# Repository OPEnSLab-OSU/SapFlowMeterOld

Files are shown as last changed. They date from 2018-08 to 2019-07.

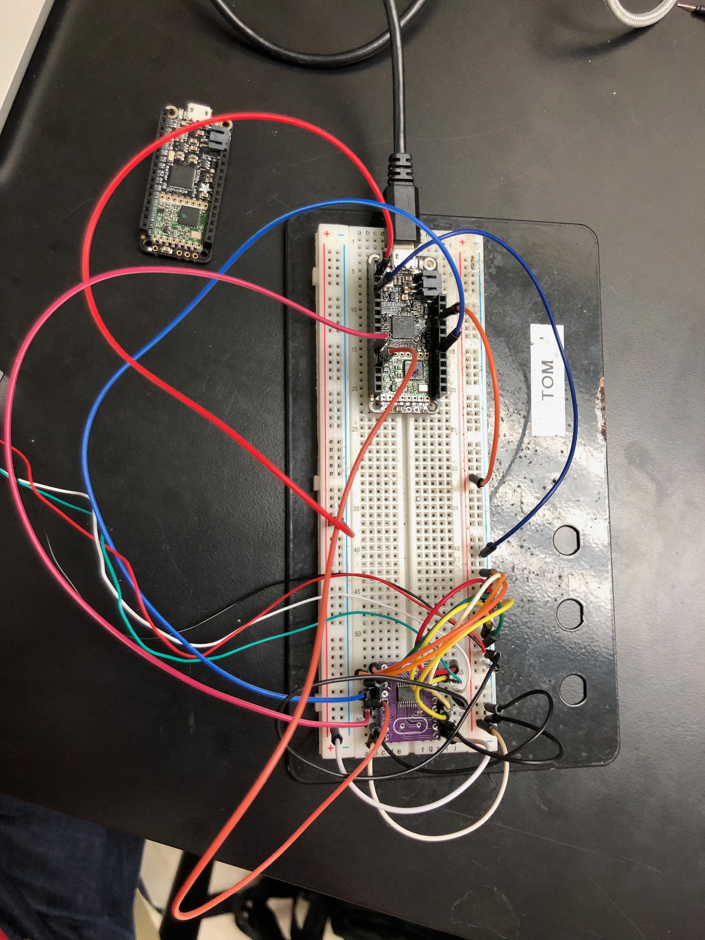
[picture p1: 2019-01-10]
MonitorDMS2/IMG_0117.jpeg

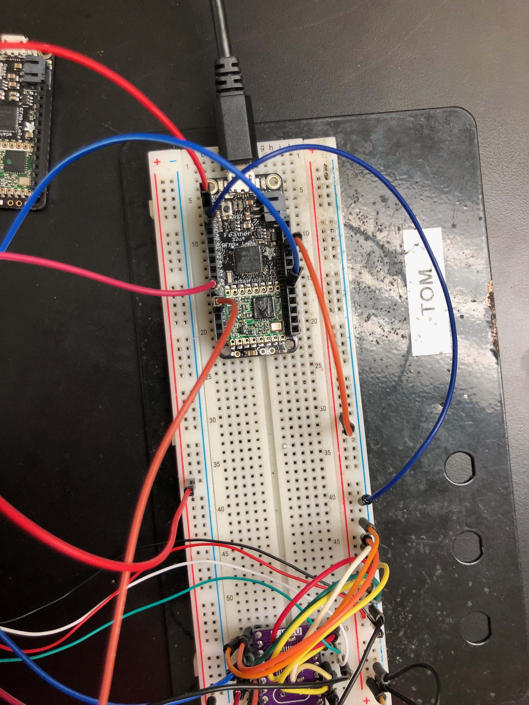
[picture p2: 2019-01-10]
MonitorDMS2/IMG_0116.jpeg

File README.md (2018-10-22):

# Sap Flow Meter

This is the primary location of the Sap Flow Meter project code, which is a modified code of Project LOOM code by OPEnS Lab, and PCB designs, by using EAGLE CAD PCB designing tool.

## Table of Contents

1. [Installation](#installation)
2. [Device Support](#device-support)
3. [Communication Platforms](#communication-platforms)
4. [Device Configuration](#device-configuration)
	1. [Enable sap flow meter](#Enable-sap-flow-meter)
	2. [HUB options](#HUB-options)
	3. [NODE options](#NODE-options)

## Installation

The Loom Library, and any dependencies, need to be placed into the Arduino libraries folder, i.e:

Document > Arduino > Libraries

## Device Support

- Arduino Feather M0

## Communication Platforms

WiFi and LoRa have had the most attention in development and thus have the most support and options, especially WiFi, as that is currently the only to communicate with a computer running Max/MSP. Other platforms have been implemented however. Below is the table of device inputs and outputs currently implemented, planned, or in consideration (bold for well implemented, * if partially implemented or in need of testing to be considered well implemented, plaintext if planned but not implemented, ? if in consideration). The top section is device-device communication platforms, and the bottom section are platforms that do not necessarily transmit directly to another Loom device

| Inputs | Outputs | Comments |
| --- | --- | --- |
| **LoRa** | **LoRa** | Implemented | 
| Ethernet | Ethernet* | Currently only used with hubs, expansion in progress |
| GSM | GSM* | Currently only one device, so outputs MQTT via GSM, but no GSM receiving yet |
| Google Sheets  | Google Sheets (PushingBox)* | Works as output, looking for ways of improving the pipline |
| SD card | **SD card** | Works as output, considering as input |
| Serial | **Serial** | Works for output. Serial as input may or may not be useful (is how Fona is tested) |

## Device Configuration

The configuration of the code to upload and flash to devices is set in the config.h file. This file presents the options that can be set or toggled to achieve a particular behavior. The preprocessor uses these definitions to select the necessary declarations, variables, and functions automatically. 

Currently changes to the config need to be done manually in the file itself.

The configuration file is used in conjunction with preprocessor statements to essentially built the specificed sketch. Any options that can be set or toggled, or any specification of hardware (e.g. relay switch for HRM, and analog sensor for NTC thermistors) being used occur in (and only in) this config.h.

### Enable sap flow meter

Firstly, it is necessry to toggle "is_sapflow"

```cpp
// --- Prebuilt Devices ---
#define is_ishield      0	// 1 to specify using Ishield (should enable only wifi as communication platform)
#define is_multiplexer  0	// 1 if tca9548a Multiplexer is being used. (Further customization in advanced options)
#define is_sapflow      1 
#define is_evaporimeter 0
```

### Manipulate options

Set ether HUB or Node(probe meter)

### HUB options
- Set hub_node_type to be 0
- Set CHANNEL to be 1 - 8
- Set is_lora to be 1 if you want to communicate to receive data from node through LoRa. Default is 1.
- Set is_rtc to be 1 if you want to log timestamp
- Set is_sd to be 1 if you want to store recieved data in micro sd card
- If you want to rename excel file to be stored in the sd card, change char FileName[] = "file_name.CSV"; The file name should be short length to avoid any miscellenous error.

```cpp
// --- Sapflowmeter Options ---
#if is_sapflow == 1
	#define hub_node_type    0      // 0: hub, 1: node
  #define probe_type       0      // 0: TDM, 1: HRM
  #define sensor_type      1      // 0: NTC, 1: RTD
  #define CHANNEL          1      // Channel to use. Set to 1-8 for channels A-H, respectively. Alternatively can define to -1 to used advanced option INIT_INST
  #define REQUEST_SETTINGS 0      // 1 to request channel settings from Max Channel Manager, 0 to not
  #define AUTO_NAME        0      // 1 to enable naming device based on configured settings (if not set manual name in advanced options)
  #define is_lora          1      // enable LoRa
  #define is_rtc           1      // enable rtc
  #define is_sd            1      // enable microsd logger
   char FileName[]       =     "HUB1019.CSV";
```

- set is_ethernet to be 1 if you want to send data through ethernet
- set is_fona to be 1 if you want to send data through 2G network
- set is_pushingbox 1 if you want to store data in google sheet
- To store data in google sheet, it is necesary to define spreadsheet ID of google sheet that you want use and device ID. There is detail directions to setup pushingbox and googlesheet in the next section.

```cpp
  #if hub_node_type == 0       // if is hub
    #define is_ethernet   0
    #define is_fona       1
    #define is_pushingbox 1
    #if is_pushingbox == 1
      #define spreadsheet_id "17XjrTjXENChYsHMVvKgePg8rsohwz0hyASkdeZZKROk"   // This is Dongjun's Sapflow spreadsheet
      char device_id[]   =   "v4099B684340616E";
    #endif // of is_pushingbox
  #elif hub_node_type == 1     // if is node
  .
  .
  .
  ```
### NODE options

- Set hub_node_type to be 1
- Set probe_type to be 0: TDM or 1:HRM
- Set sensor_type to be 0: NTC thermister or 1: RTD sensor. There will be more options for other sensors(eg. k type thermometer) later.
- Set CHANNEL to be 1 - 8
- Set is_lora to be 1 if you want to communicate to send data to HUB through LoRa. Default is 1.
- Set is_rtc to be 1 if you want to log timestamp
- Set is_sd to be 1 if you want to store measured data in micro sd card
- If you want to rename excel file to be stored in the sd card, change char FileName[] = "file_name.CSV"; The file name should be short length to avoid any miscellenous error.

```cpp
// --- Sapflowmeter Options ---
#if is_sapflow == 1
  #define hub_node_type    1      // 0: hub, 1: node
  #define probe_type       0      // 0: TDM, 1: HRM
  #define sensor_type      1      // 0: NTC, 1: RTD
  #define CHANNEL          1      // Channel to use. Set to 1-8 for channels A-H, respectively. Alternatively can define to -1 to used advanced option INIT_INST
  #define REQUEST_SETTINGS 0      // 1 to request channel settings from Max Channel Manager, 0 to not
  #define AUTO_NAME        0      // 1 to enable naming device based on configured settings (if not set manual name in advanced options)
  #define is_lora          1      // enable LoRa
  #define is_rtc           1      // enable rtc
  #define is_sd            1      // enable microsd logger
   char FileName[]       =     "TDM0731.CSV";
```

- Set is_sht31d to be 1 if you want to measure ambient temperature and humidity
- Set is_decagon to be 1 if you want to use soil moisture sensor
- If you use HRM probe, you can modify heat pulse duration. Default is 2.5 sec. The heater turns on for 2.5 sec and turn off for 2.5 sec repeatedly during heat duration.
- If you want to change data transmission interval, modify senddelay. 60000 for 1 min, 900000 for 15 min, 1800000 for 30 min. Default is 900000.
- If you want to change heat duration(Period that heater turns on),  change heatduration. Defualt for TDM is 240000(4 min), and for HRM is 120000 (2 min). The heater is turned on before data transmission time for the heat duration and turned off 1 min after data transmission. (For example, let's assume the code was initialized at 13:00. If senddelay is 15 min and heatduration is 4min, the heater is turned on at 13:11(4 mins before send interval). Probe meter measures and sends data at 13:15. The heater is turned off at 13:16. After this iteration, the heater is turned on again at 13:26. It sends data at 13:30. The heater is turned off at 13:31. Repeat this process until the battery is dead or probe meter is off)

```cpp
  .
  .
  .
  #elif hub_node_type == 1     // if is node
    #define num_analog    2      // two temperature sensors
    #define is_sht31d     1      // Ambient Temperature / Humidity
    #define is_decagon    1      // Soil moisture
    #define heatpulse     2500   // For HRM probe heat pulse (e.g 2500:2.5 sec) 
    #define senddelay     900000 // send data every 2500(=2.5s), 60000(=1m), 300000ms(=5m), 600000ms(=10m), 900000ms(=15m)
    #if probe_type == 0      // 0:TDM, 1: HRM
      #define heatduration  240000  // Turn on heater for 4 min
    #elif probe_type == 1
      #define heatduration  120000  // Turn on heater for 2 min
    #endif //of probe_type
  #endif // of hub_node_type
```

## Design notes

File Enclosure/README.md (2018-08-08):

# Sap Flow Meter: CAD

## Table of Contents

1. [Sap flow meter Top](https://a360.co/2OUiD7d)
2. [Sap flow meter Bottom](https://a360.co/2OUiD7d)

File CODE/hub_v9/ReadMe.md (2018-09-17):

# Project Loom: Library

This is the primary location of the Project LOOM code, consolidated into place with a single Arduino .ino sketch built with code selected by the preprocessor based on the configuration file. 

## Table of Contents

1. [Installation](#installation)

2. [Device Support](#device-support)

3. [Communication Platforms](#communication-platforms)

4. [Device Configuration](#device-configuration)

5. [Max/MSP](#max/msp)

6. [Library Architecture](#library-architecture)
    1. [Overall Structure](#overall-structure)
        1. [Example Library Include Hierarchy](#example-library-include-hierarchy)
    2. [Adding to the Library](#adding-to-the-library)
    3. [Adding to the Message Router](adding-to-the-message-router)

7. [Channels](#channels)
    1. [Implementation](#implementation)
    2. [Additional Devices](#additional-devices)

8. [Configuration File](#configuration-file)

9. [API](#api)
    1. [Includes](#includes)
    2. [Setup](#setup)
    3. [Main Loop Functions](#main-loop-functions)
        1. [Receive Bundle](#receive-bundle)
        2. [Process Bundle](#process-bundle)
        3. [Measure Sensors](#measure-sensors)
        4. [Package Data](#package-data)
        5. [Send Bundle](#send-bundle)
        6. [Additional Loop Checks](#additional-loop-checks)
        	. [Minimal Working Example](#minimal-working-example)	

10. [SD Card Support](#sd-card-support)

11. [Real-Time Clock Support](#real-time-clock-support)

12. [Arduino IDE Setup](#arduino-ide-setup)

13. [Building and Uploading Code Without The IDE](#building-and-uploading-code-without-the-ide)

14. [Configuration Conflicts](#configuration-conflicts)

## Installation

The Loom Library, and any dependencies, need to be placed into the Arduino libraries folder, i.e:

Document > Arduino > Libraries

## Device Support

- Adafruit Feather M0
- Adafruit Feather 32u4

## Communication Platforms

WiFi and LoRa have had the most attention in development and thus have the most support and options, especially WiFi, as that is currently the only to communicate with a computer running Max/MSP. Other platforms have been implemented however. Below is the table of device inputs and outputs currently implemented, planned, or in consideration (bold for well implemented, * if partially implemented or in need of testing to be considered well implemented, plaintext if planned but not implemented, ? if in consideration). The top section is device-device communication platforms, and the bottom section are platforms that do not necessarily transmit directly to another Loom device

| Inputs | Outputs | Comments |
| --- | --- | --- |
| **WiFi** | **WiFi** | Implemented |
| **LoRa** | **LoRa** | Implemented |
| nRF* | nRF* | May need more testing to be 'proven' |
| Ethernet | Ethernet* | Currently only used with hubs, expansion in progress |
| GSM | GSM* | Currently only one device, so outputs MQTT via GSM, but no GSM receiving yet |
| Bluetooth | Bluetooth | Planned |
| | | |
| Google Sheets? | Google Sheets (PushingBox)* | Works as output, looking for ways of improving the pipline |
| Adafruit IO* | Adafruit IO* | Could use more robust integration |
| IFTTT? | IFTTT? | Currently, IFTTT works only as output though Adafruit IO |
| SD card? | **SD card** | Works as output, considering as input |
| Serial? | **Serial** | Works for output. Serial as input may or may not be useful (is how Fona is tested) |

## Device Configuration

The configuration of the code to upload and flash to devices is set in the config.h file. This file presents the options that can be set or toggled to achieve a particular behavior. The preprocessor uses these definitions to select the necessary declarations, variables, and functions automatically. 

Currently changes to the config need to be done manually in the file itself. A script to automate this process from the command line, and ultimately Max, is in progress.

## Max/MSP

The associated [Loom Data Processors](https://github.com/OPEnSLab-OSU/InternetOfAg/tree/master/Max) and control modules are made as patches in Max/MSP. The Max interfaces are not strictly necessary for using this library, but provide convenient features and means of interacting with your Loom devices / network.

## Librarary Architecture

The LOOM Library is the answer to the growing set of code to drive Project LOOM's supported devices, hardware, and communication platforms. The set of possible combinations of device configurations makes it unfeasable for LOOM developers and users alike to manage sketches with desired functionality. Instead, a configuration file effectively creates the desired sketch dynamically. A loom_preamble file selects entire files to include, each of which may also contain additional preprocessor statements.

### Overall Structure

The LOOM Library is effectively an aggregate of all of the functionality possible within the entirety of the supported devices, sensors, and actuators. The user then specifies the needs of their sketch inside the config.h. Based on the needs of the sketch, the requisite files, functions, and logic will be dynamically included such that only what is needed by the sketch is uploaded to the device. loom_preamble.h uses config.h to know which files to include, these files in turn then include the libraries they need. loom_common.h is also always present as it has the LOOM_begin() function, which sets up all the modules and sensors being used by the sketch. 

#### Example Library Include Hierarchy

The hierarchy of included files looks something like the following (example if building for Ishield device on Feather M0 WiFi). 

**Note** – bolded are files that are always necessary and thus included, independent of config.h. In angle brackets are non-Loom dependencies.

- Ishield_Example.ino
  - **Config.h**
  - **Loom_preamble.h** (likely to be renamed)
    - **<OSCBundle.h>**
    - Loom_translator.h
    - <Adafruit_SleepyDog.h>
    - <SPI.h>
    - loom_analog.h
    - loom_neopixel.h
      - <Adafruit_NeoPixel.h>
    - loom_mpu6050.h
      - <I2Cdev.h>
      - <Wire.h>
      - <MPU6050_6Axis_MotionApps20.h>
    - loom_wifi.h
      - <WiFi101.h>
      - <WiFiUDP.h>
    - **loom_flash.h**
      - <FlashStorage.h>
    - **loom_common.h**

### Adding to the Library

New sensor and actuator support can be added by filling out the loom_mod_template.h file with relevant code. This template ensures that the code for each piece of hardware conforms to a standard format, making it easier to read and understand.

New files should be added #included in the loom_preamble.h file after config.h but generally before loom_flash.h and loom_common.h.

There are plans/consideration for a script that will handle most of the additions for a user based on various provided parameters / needs as current additions generally need to modify the config, preamble, loom_commom (sometimes), and loom_interface files in a mostly boiler plate fashion in addition to the new device-specific file.

### Message Router

#### Intro to Route and Dispatch of Message Router

Custom functions can be added to the message router. The message router is called via:

```
bndl->route(configuration.packet_header_string, msg_router);
```

From the `process_bundle` function in the 'loom_interface.h' file. The message router checks any OSC messages that it receives, and if the message's address string matches one of the dispatch calls in the router, then the message gets forwarded to a function designed to handle / process messages with that address string. This usually entails reading the arguments to the message (which should be sent in an order / format known by the function that will handle the processing).

The dispatch calls in the message router take the following form:

```
msg.dispatch("/address", processing_function, addrOffset);
```

An example of a dispatch that takes a message that has an address of the device identifying string followed by "setID", and calls a function `set_instance_num` (which sets the device instance number) would be:

```
msg.dispatch("/SetID", set_instance_num, addrOffset);
```

The reason only the `/SetID` is provided and not something like `/LOOM/Ishield7/SetID` is because the aforementioned route function checks for message addressed to the device, which in this case is identified by `/LOOM/Ishield7`, and passes only the remaining part of the address to the message router. Messages that do not start with the device indentifying string are not sent to the message router.

#### Adding Custom Functions to Message Router

There are a few steps that must be followed in order to get a custom function to be callable by the message router. These are:

- Write your function in the correct format
- Add the function prototype to the top of loom_msg_router.h file
- Add the dispatch call to the msg_router function

**Writing Your Function**

All function that are called by the message router need to take only an OSC message by reference, and return nothing. Thus a function skeleton would look like:

```
void your_function(OSCMessage &msg)
{
	// process the message forwarded from msg_router
}
```

Inside this function is generally where you will process the message (if you need, you can add auxiliary function(s), to do some of the processing/handling - these do not have constraints on the parameters or return value). The following OSC methods are recommended for extracting the arguments from the message. (The below list is not exhaustive, see the [OSC API](https://github.com/CNMAT/OSC/blob/master/API.md) for more functions)

**`msg.size()`** Returns the number of arguments in the the message

**`msg.getType(index)`** Returns the type of the argument at `index`, `i` for integer, `f` for float, and `s` for string. Useful in combination with switch statement to select which of the following three functions to call.

**`msg.getInt(index)`** Returns argument to message that is an integer at `index` if argument is indeed an integer and there is an argument at that index

**`msg.getFloat(index)`**Returns argument to message that is a float at `index` if argument is indeed a float and there is an argument at that index

**`msg.getString(index)`**Returns argument to message that is a string at `index` if argument is indeed a string and there is an argument at that index

**`msg.getAddress(buf, 0);`** Copies address of message into char array called `buf`

**Adding the Function Prototype**

Add the protype of the function you wrote, e.g:

```
void your_function(OSCMessage &msg);
```

to the `Custom Function Prototypes` section at the top of the `loom_msg_router.h` file. (Don't forget the semicolon). Should be no need to add the prototypes for any auxililary functions called by the `your_function`.

**Adding the Dispatch Call**

At the bottom of the message router, add:

```
msg.dispatch("/command/string", your_function, addrOffset);
```

Where

-  `/commmand/string` is the section after the device identifying string that is being used to select which function to dispatch a message to. This should be descriptive but not overly long. In the above example,  the string `setID` was used to check if the message should be forwarded to `set_instance_num`
- `your_function` is the name of the function you want to be called if the message matches the device identifying string and command string.
- `addrOffset` should stay as it is, this is an integer value passed in from the `bndl->route(...)` call, and simply specifies where in the message string to start looking for the command section (i.e. right after the device identifying string)

## Channels

The LOOM library and associated Max/MSP processors are designed to use channel based interfaces by default. Channel interfaces abstract device instance number, UDP port, and IP address into a single letter A, B, C, … H. 

The channels are purely a convenience, and the devices can operate without any notion of channels in the firmware and/or Max patches.

### Implementation
A common port is used for the communication of device settings in order to allow the Max patches to communicate with devices in a consistent manner if the instance number, UDP port, or IP (i.e. the channel information) address are unknown.

**Common Port:** 9440 

**Device Unique Channnel Data:** 9441 – 9448

Channel A:	Instance # = 1		UDP Port = 9441	

Channel B:	Instance # = 2		UDP Port = 9442

• • •

Channel H:	Instance # = 8		UDP Port = 9448

**IP Address:** Automatically assigned to devices by one's router. Max interfaces will automatically fetch IP address of selected device. If not using the channels feature implemented in the Loom Max interfaces, then Loom Debug mode may need to be enabled, or the user may need to add custom code, in order to obtain the device's IP address.

### Additional Devices

The Max interfaces presently support 8 concurrent channels, the library itself poses no such restrictions and using custom Max interfaces can allow for the control of more devices.

## Configuration File

The configuration file is used in conjunction with preprocessor statements to essentially built the specified sketch. Any options that can be set or toggled, or any specification of hardware (e.g. sensors and actuators) being used occur in (and only in) this config.h.

Any options for custom additions to the library should be added only to the configuration file.

The config.h file needs to be included before the library itself, so that the configuration can be used to define the necessary subset of the library.

## API

### Includes

Only the configuration and the library are necessary in the .ino sketch. All necessary dependecies of the Loom Library are automatically included. 

**Note:** The config.h file must precede the library

```cpp
#include "config.h"
#include "loom_preamble.h"
```

### Setup

All Loom and device setup is called dynamically within Loom_begin(). A simple setup function would simply be:

```cpp
void setup() 
{
	Loom_begin();	
    
    // Any custom setup code
}
```

### Main Loop Functions

The Loom Library has six primary interface function to call. With just these, a fully functional sketch can be made. Custom code can be inserted before, between, and after any of the interface functions, but changing the relative ordering of the interface functions is not recommended unless you know what you are doing.

#### Receive Bundle

Fills an OSC bundle with packets received the specified platform if data exists and platform is enabled.

```cpp
// Receive bundles
//  takes bundle to be filled and wireless platforms [WIFI, LORA, NRF]
receive_bundle(&bndl, WIFI);
```

- **bndl** – The bundle to fill
- **platform** – The wireless platform to receive on, the values are encoded to a Platform enum to reduce chance for errors

#### Process Bundle

Examine the provided OSC bundle (presumably filled via receive_bundle(). If bundle is not empty,  has no errors, and is addressed to this device, then attempt to perform action specified.

```cpp
// Process bundle (nothing will happen if bndl is empty), bundle is emptied after processing
process_bundle(&bndl);
```

- **bndl** – The bundle to be processed

#### Measure Sensors

Update stored readings from sensors by calling measure on each enabled sensor.

```cpp
// Update stored readings from sensors
measure_sensors();
```

#### Package Data

Fill the provided OSC bundle with latest stored sensor readings

```cpp
// Populate bundle to send with sensor values
package_data(&send_bndl);
```

- **send_bndl** – The OSC bundle to be filled

#### Send Bundle

Sends a packaged bundle on the specified platform

```cpp
// Send the bundle
//  takes bundle to be filled and wireless platforms [WIFI, LORA, NRF]
send_bundle(&send_bndl, WIFI);
```

- **bndl** – The bundle to be sent
- **platform** – The wireless platform to send on, the values are encoded to a Platform enum to reduce chance for errors

#### Additional Loop Checks

Performs any miscellaneous Loom tasks that happen each loop iteration, but are not handled by any of the other 5 interface functions, such as delays between loop iterations and checking a device button has been held for a set amount of time.

```cpp
// Loop checks and sleep between iterations if enabled
additional_loop_checks();
```

### Minimal Working Example

This example is fully functional. It assumes that WiFi has been specified as a wireless communication platform in the config.h file.

```cpp
#include "config.h"
#include "loom_preamble.h"

void setup() 
{
	Loom_begin(); // LOOM_begin calls any relevant LOOM device setup functions
	// Any custom setup code
}

void loop() 
{
	OSCBundle bndl, send_bndl; 
	
	receive_bundle(&bndl, WIFI);
	process_bundle(&bndl);
	measure_sensors();
	package_data(&send_bndl);
	send_bundle(&send_bndl, WIFI);
	additional_loop_checks();
} 
```

## SD Card Support

The Loom library extends the Arduino SD library to have more features, mostly tailored towards using common data structures used by the library.

Namely, support for printing:

- Single elements (int, floats, c-strings, Strings)
- Arrays (ints, floats, c-strings, Strings)
- Bundles (single or multi-msg format)

Additionally, if used with MaxMSP, there is support for sending commands to enable / disable the logging of bundles the device receives (also works without Max).

## Real-Time Clock Support

The Loom library supports two RTC devices:

- Adafruit DS3231 
- Adafruit PCF8523

Currently, interrupts are only supported via the DS3231, with the PCF8523 mostly being used in conjunction with an SD card (as Adafruit Adalogger featherwing has PCF8523 and SD card holder) to provide timestamps.

The Loom Library has support for both devices for returning strings of the date, time, or weekday. Additional timer functions are provided for the DS3231.

## Arduino IDE Setup

Make sure to download the dependencies of the Loom Library from:

https://github.com/OPEnSLab-OSU/InternetOfAg/tree/master/Dependencies 

and install the libraries with the Arduino IDE, as described here:

https://www.arduino.cc/en/guide/libraries

## Building and Uploading Code Without The IDE

Work is currently be done on investigating and implementing a script that will build the config.h file from the command line, taking the options as arguments. A corresponding Max interface will be made to provide a GUI to these options. The interface will pair with the one to subsequently build and upload code to devices.

The design is planned to be as follows:

- Generate the config file from command line 
  - Arguments to used set options, have default values if none specified
  - Sent to a Python script, inserting the parameters in the relevant locations of the config file
- Be able to call this script from Max
- Use Max to create a graphical interface of toggles / inputs corresponding to the script arguments.
  - Error checking (i.e., of selection conflicts) can be performed in the script or Max, but would doing so in Max would give users immediate feedback on invalid combinations

## Configuration Conflicts

The following combinations of options in the configuration file result in various conflicts (e.g. of dependencies) that are known to result in errors or undefined behavior. Such conflicts are also mentioned in the config.h file itself.

- LoRa + nRF
- is_sleep_period + LoRa (Adafruit_ASFcore-master/tc_interrupt.c:140: multiple definition of 'TC3_Handler')

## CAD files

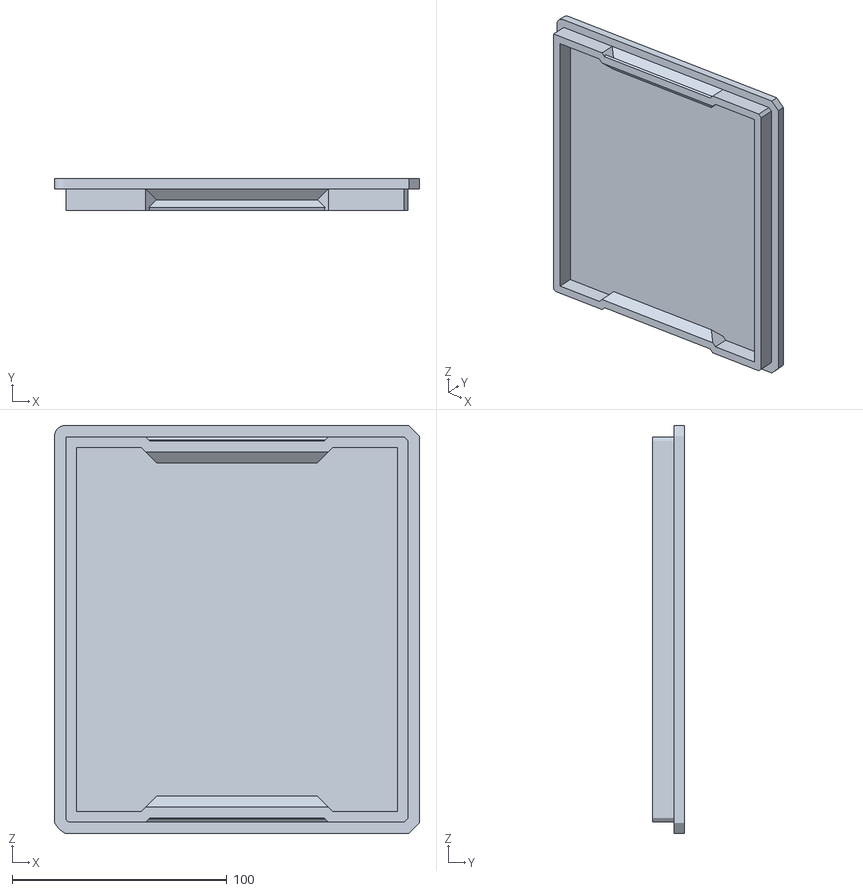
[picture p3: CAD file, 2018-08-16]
Enclosure/Sap_Base_Top_v2.stl
170.0 x 15.0 x 190.0

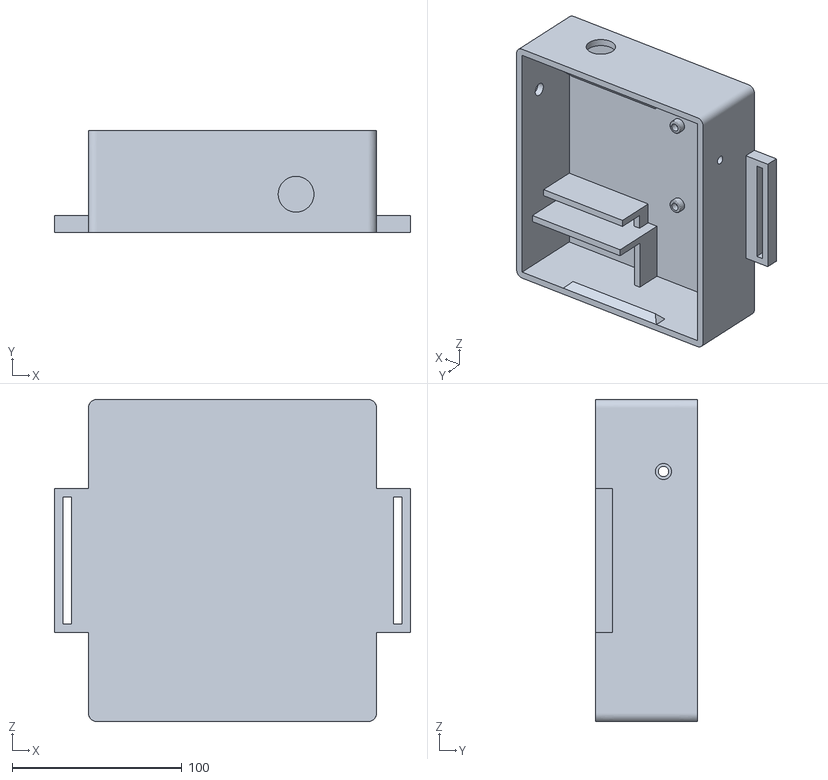
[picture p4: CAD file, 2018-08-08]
Enclosure/Sap_Base_Bottom_v2.stl
210.0 x 60.0 x 190.0

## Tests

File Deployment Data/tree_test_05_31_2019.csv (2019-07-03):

K-Type Top (C) | K-Type Bottom (C) | Set Count | Total Count
K-Type Top (C) | K-Type Bottom (C) | Set Count | Total Count
K-Type Top (C) | K-Type Bottom (C) | Set Count | Total Count
K-Type Top (C) | K-Type Bottom (C) | Set Count | Total Count
K-Type Top (C) | K-Type Bottom (C) | Set Count | Total Count
K-Type Top (C) | K-Type Bottom (C) | Set Count | Total Count
K-Type Top (C) | K-Type Bottom (C) | Set Count | Total Count
K-Type Top (C) | K-Type Bottom (C) | Set Count | Total Count
K-Type Top (C) | K-Type Bottom (C) | Set Count | Total Count
22.13 | 21.38 | 22.02 | 21.52 | 21.98 | 21.27 | 21.91 | 21.21 | 21.77 | 20.98 | 21.73 | 20.82 | 1 | 0
K-Type Top (C) | K-Type Bottom (C) | Set Count | Total Count
21.50 | 20.38 | 21.43 | 20.30 | 21.59 | 20.35 | 21.52 | 20.24 | 21.44 | 20.23 | 21.38 | 20.48 | 1 | 0
K-Type Top (C) | K-Type Bottom (C) | Set Count | Total Count
K-Type Top (C) | K-Type Bottom (C) | Set Count | Total Count
20.05 | 18.91 | 1 | 1
K-Type Top (C) | K-Type Bottom (C) | Set Count | Total Count
K-Type Top (C) | K-Type Bottom (C) | Set Count | Total Count
K-Type Top (C) | K-Type Bottom (C) | Set Count | Total Count
17.48 | 18.77 | 1 | 1
17.49 | 18.34 | 2 | 2
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

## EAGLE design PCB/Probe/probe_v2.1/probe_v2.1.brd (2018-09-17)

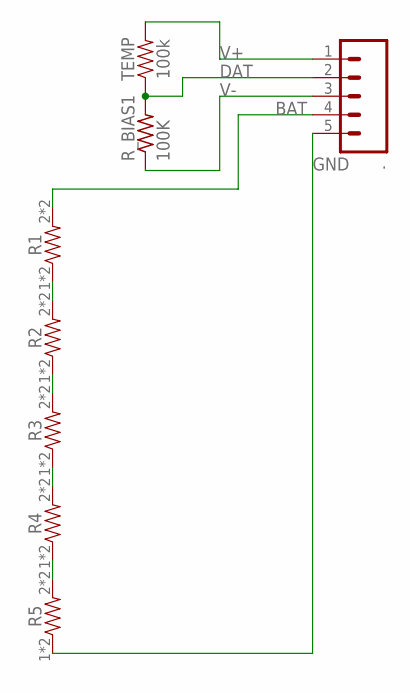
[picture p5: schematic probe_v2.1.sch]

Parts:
.: CONN_05NO_SILK; 1X05_NO_SILK
R1, R2, R3, R4, R5: DRES; 0603
R_BIAS1: 100K; 0805-THM
TEMP: 100k; 0603

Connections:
BAT: ..4, R1.2, R1.P$2 (2)
DAT: ..2, R_BIAS1.2, TEMP.1
GND: ..5, R5.1, R5.P$1 (1)
unnamed: R2.1, R2.P$1 (1), R3.2, R3.P$2 (2)
unnamed: R1.1, R1.P$1 (1), R2.2, R2.P$2 (2)
unnamed: R3.1, R3.P$1 (1), R4.2, R4.P$2 (2)
unnamed: R4.1, R4.P$1 (1), R5.2, R5.P$2 (2)
V+: ..1, TEMP.2
V-: ..3, R_BIAS1.1

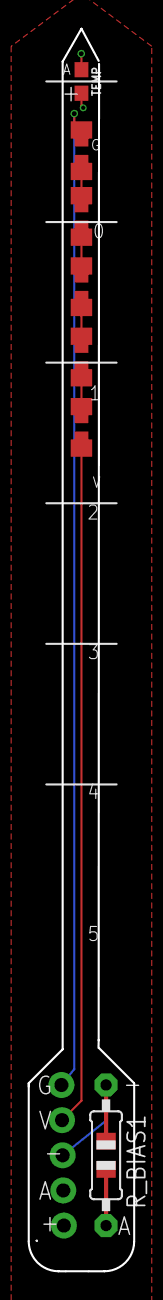
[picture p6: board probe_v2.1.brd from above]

Board: 4 copper layers, 7.6 x 89.8 mm, 8 parts (0 on the bottom side), 9 nets.

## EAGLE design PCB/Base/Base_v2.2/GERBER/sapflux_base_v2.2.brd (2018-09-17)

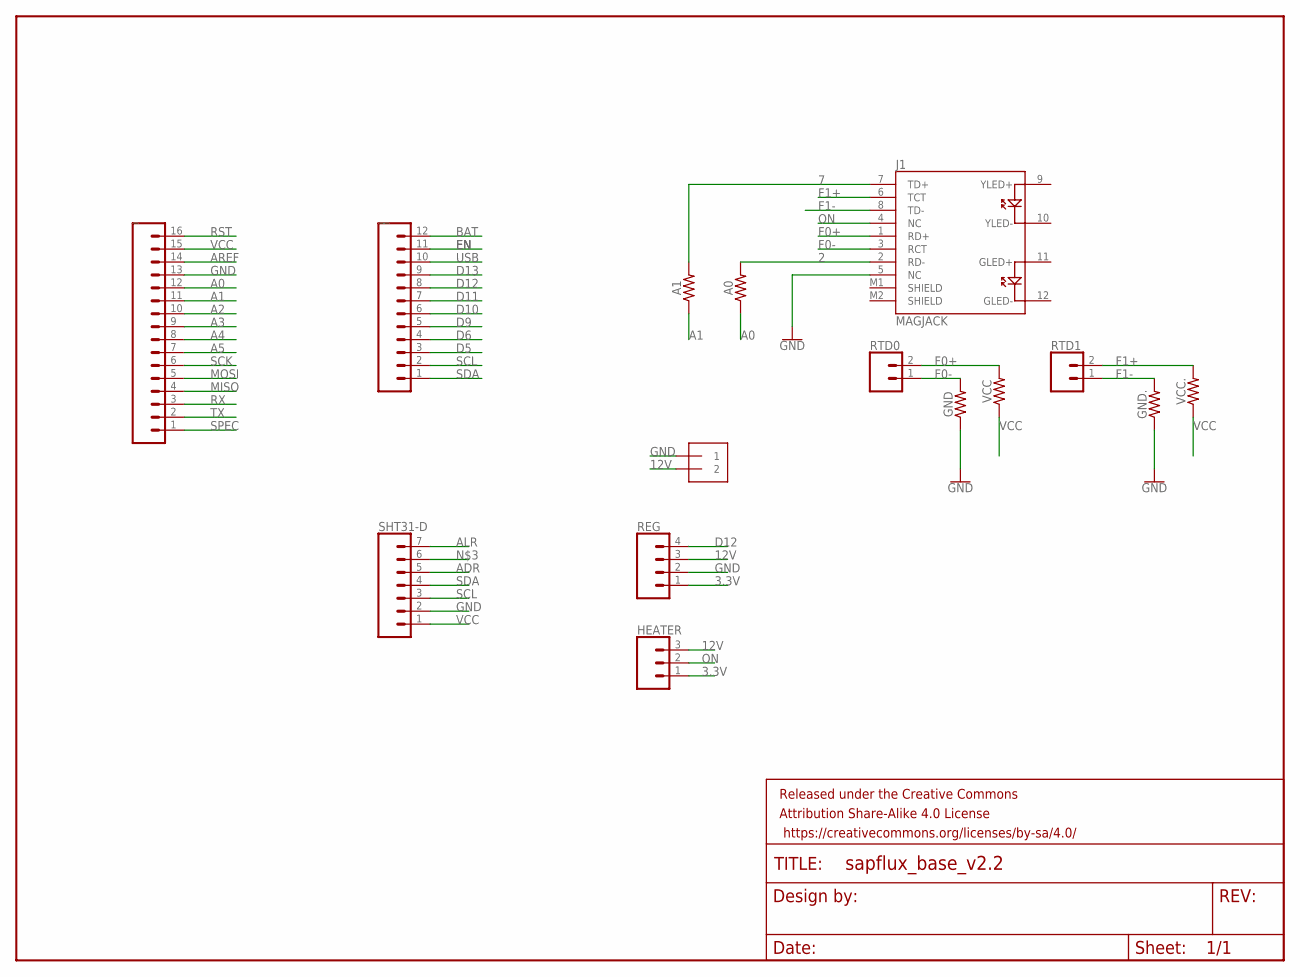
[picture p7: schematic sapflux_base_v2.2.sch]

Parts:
.: 1X2-3.5MM
A0, A1: 1.8MOHM; 0603
FRAME1: FRAME-LETTER; CREATIVE_COMMONS
GND, GND.: 1.8MOHM; 0603
HEATER: CONN_03; 1X03
J1: MAGJACK
REG: CONN_04; 1X04
RTD0, RTD1: CONN_02; 1X02
SHT31-D: CONN_07; 1X07
VCC, VCC.: 1.8MOHM; 0603
_: CONN_16; 1X16
__: CONN_12; 1X12

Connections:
2: A0.2, J1.2 (RD-)
3.3V: HEATER.1, REG.1
7: A1.2, J1.7 (TD+)
12V: ..2, HEATER.3, REG.3
A0: A0.1, _.12
A1: A1.1, _.11
A2: _.10
A3: _.9
A4: _.8
A5: _.7
ADR: SHT31-D.5
ALR: SHT31-D.7
AREF: _.14
BAT: __.12
D5: __.3
D6: __.4
D9: __.5
D10: __.6
D11: __.7
D12: REG.4, __.8
D13: __.9
EN: __.11
F0+: J1.1 (RD+), RTD0.2, VCC.2
F0-: GND.2, J1.3 (RCT), RTD0.1
F1+: J1.6 (TCT), RTD1.2, VCC..2
F1-: GND..2, J1.8 (TD-), RTD1.1
GND: ..1, GND.1, GND..1, J1.5 (NC), REG.2, SHT31-D.2, _.13
MISO: _.4
MOSI: _.5
ON: HEATER.2, J1.4 (NC)
RST: _.16
RX: _.3
SCK: _.6
SCL: SHT31-D.3, __.2
SDA: SHT31-D.4, __.1
SPEC: _.1
TX: _.2
USB: __.10
VCC: SHT31-D.1, VCC.1, VCC..1, _.15

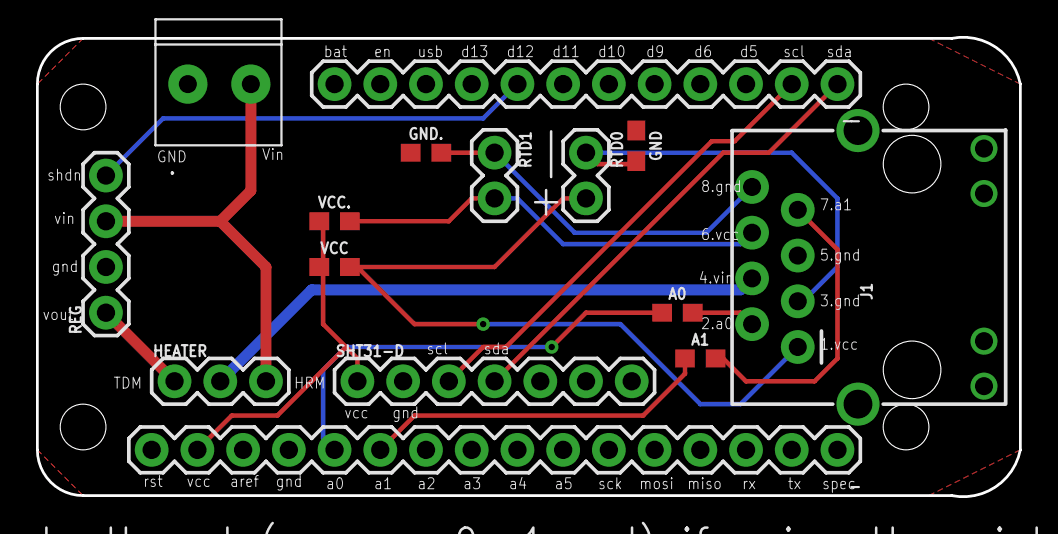
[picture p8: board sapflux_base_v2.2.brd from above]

Board: 2 copper layers, 54.6 x 25.5 mm, 16 parts (0 on the bottom side), 16 nets.

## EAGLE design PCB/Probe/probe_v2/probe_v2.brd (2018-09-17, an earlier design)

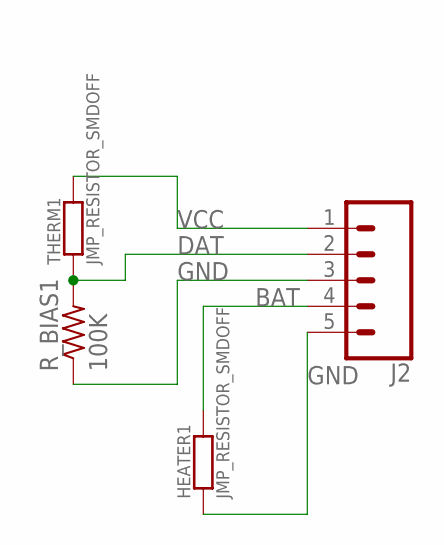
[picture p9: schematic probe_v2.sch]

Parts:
HEATER1: JMP_RESISTOR_SMDOFF; JMP_OFF_SMD
J2: CONN_05NO_SILK; 1X05_NO_SILK
R_BIAS1: 100K; 0805-THM
THERM1: JMP_RESISTOR_SMDOFF; JMP_OFF_SMD

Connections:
BAT: HEATER1.2, J2.4
DAT: J2.2, R_BIAS1.2, THERM1.1
GND: HEATER1.1, J2.3, J2.5, R_BIAS1.1
VCC: J2.1, THERM1.2

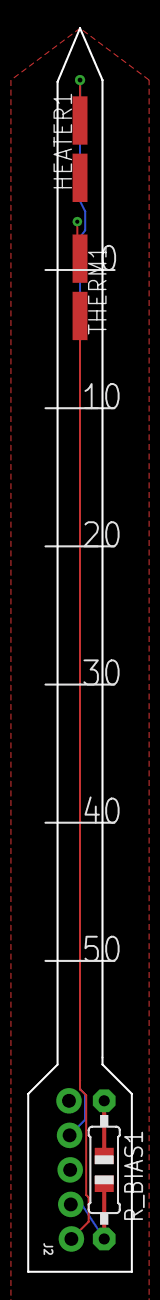
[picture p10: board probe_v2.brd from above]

Board: 4 copper layers, 7.6 x 91.4 mm, 4 parts (0 on the bottom side), 4 nets.

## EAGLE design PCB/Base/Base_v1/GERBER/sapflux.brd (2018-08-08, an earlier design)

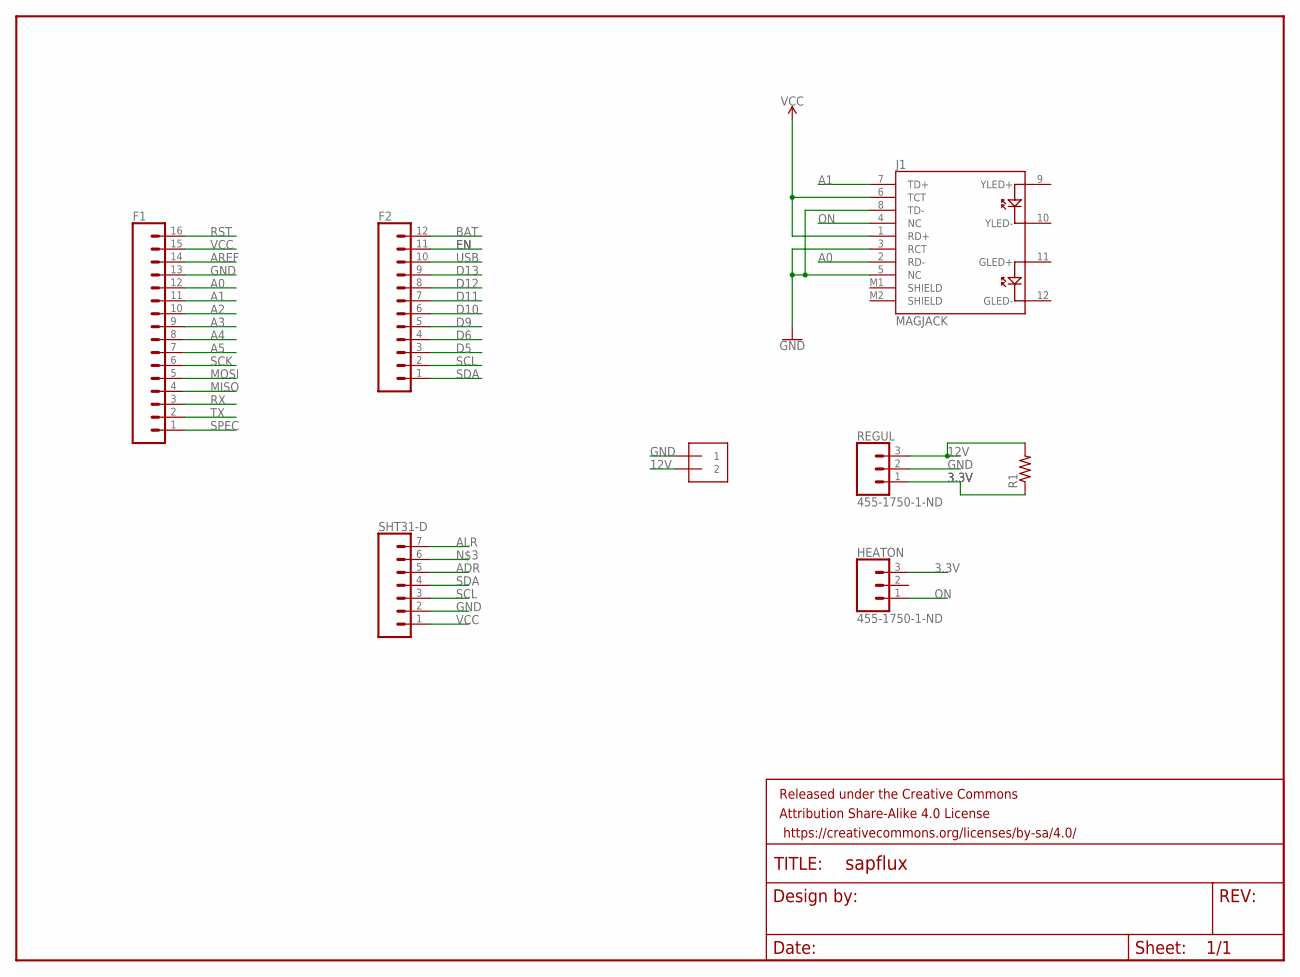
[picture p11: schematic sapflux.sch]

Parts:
F1: CONN_16; 1X16
F2: CONN_12; 1X12
FRAME1: FRAME-LETTER; CREATIVE_COMMONS
HEATON: 455-1750-1-ND; 1X03
J1: MAGJACK
J2: 1X2-3.5MM
R1: R-US_R0603; R0603
REGUL: 455-1750-1-ND; 1X03
SHT31-D: CONN_07; 1X07

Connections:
3.3V: HEATON.3, R1.1, REGUL.1
12V: J2.2, R1.2, REGUL.3
A0: F1.12, J1.2 (RD-)
A1: F1.11, J1.7 (TD+)
A2: F1.10
A3: F1.9
A4: F1.8
A5: F1.7
ADR: SHT31-D.5
ALR: SHT31-D.7
AREF: F1.14
BAT: F2.12
D5: F2.3
D6: F2.4
D9: F2.5
D10: F2.6
D11: F2.7
D12: F2.8
D13: F2.9
EN: F2.11
GND: F1.13, J1.3 (RCT), J1.5 (NC), J1.8 (TD-), J2.1, REGUL.2, SHT31-D.2
MISO: F1.4
MOSI: F1.5
ON: HEATON.1, J1.4 (NC)
RST: F1.16
RX: F1.3
SCK: F1.6
SCL: F2.2, SHT31-D.3
SDA: F2.1, SHT31-D.4
SPEC: F1.1
TX: F1.2
USB: F2.10
VCC: F1.15, J1.1 (RD+), J1.6 (TCT), SHT31-D.1

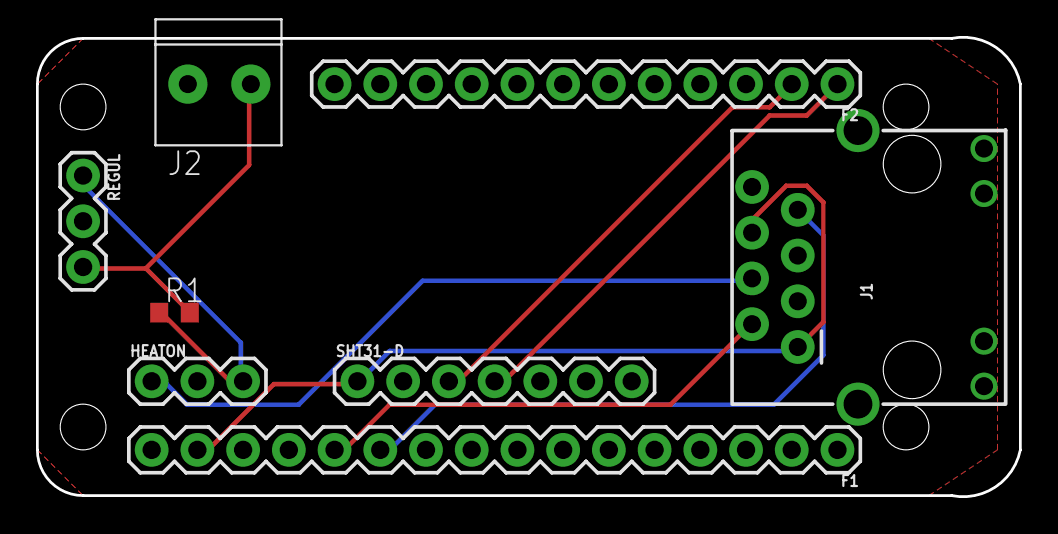
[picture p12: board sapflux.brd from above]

Board: 2 copper layers, 54.6 x 25.5 mm, 9 parts (0 on the bottom side), 9 nets.

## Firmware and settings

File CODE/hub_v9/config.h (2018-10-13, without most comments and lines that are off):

#define FAMILY "LOOM"			// Will usually be "LOOM", you can change this if you are setting up your own network
#define FAMILY_NUM       0		// Specifies the subnet of the family that the device is on. 0 for elevated permissions (can communicate with any subnet), 1-9 for normal
#define CHANNEL          7		// Channel to use. Set to 1-8 for channels A-H, respectively. Alternatively can define to -1 to used advanced option INIT_INST
#define REQUEST_SETTINGS 0		// 1 to request channel settings from Max Channel Manager, 0 to not
#define AUTO_NAME        0		// 1 to enable naming device based on configured settings (if not set manual name in advanced options)
#define CUSTOM_NAME "Custom"	// This is only used if Auto_name is set to be 0
#define LOOM_DEBUG    1		// Set to 1 if you want Serial statements from various functions to print
#define dynamic_serial_output 1 // 0 is standard operation
#define hub_node_type 0		// 0: Hub, 1: Node
#define is_repeater   0		// Sorry, this doesn't do anything yet
#define is_wifi       0		// 1 to enable WiFi
#define is_lora       0		// 1 to enable LoRa (cannot be used with nRF) (Further customization in advanced options)
#define is_nrf        0		// 1 to enable nRF (cannot be used with LoRa) (Further customization in advanced options)
#define is_ethernet   0		// 1 to enable Ethernet (a number of options below might auto enable this anyway though)
#define is_fona       0		// 1 to enable cellular via Fona (808)
#define is_bluetooth  0		// Sorry, Bluetooth is not implemented yet
#define is_pushingbox 0		// 1 to enable PushingBox (Auto enabled if using LoRa hub)
#define is_adafruitio 0		// 1 to enable Adafruit IO (currently requires WiFi)
#define is_sd         0		// 1 to enable SD card
#define is_rtc        0		// Enable RTC functionality
#define num_servos    0 	// Number of servos being used (up to 8 per shield, testing has generally only been through 1 shield)
#define num_steppers  0		// Number of stepper motors being used
#define is_relay      0		// 1 if relays are being used (enables two, on pins 5 and 6)
#define num_analog    0		// Number of analog inputs being used (0=None ; 1=A0 ; 2=A0,A1 ; 3=A0,A1,A2)
#define is_decagon    0		// 1 if GS3 Decagon is being used
#define is_tsl2591         0	// Lux Sensor
#define is_tsl2561         0	// Lux Sensor
#if is_tsl2561 == 1
	#define tsl2561_res 3 // 1 for fastest, low-res, 2 for middle, 3 for slow, high-res
	#define is_tsl2561_low   1
	#define is_tsl2561_float 1
	#define is_tsl2561_high  1
#endif
#define is_fxos8700        0	// Accelerometer / Magnetometer
#define is_fxas21002       0	// Gyroscope
#define is_zxgesturesensor 0	// ZX_Distance Sensor
#define is_sht31d          0	// Temperature / Humidity
#define is_mb1232          0	// Sonar
#define is_mpu6050         0	// Accelerometer / Gyroscope
#define is_lis3dh          0	// Accelerometer
#define is_ms5803          0	// Atmospheric Pressure / Temperature Sensor
#define is_hx711           0    // Load Cell
#if is_hx711 == 1
	#define hx711_calibration 961.275
#endif
#define is_button 		1	// 1 to enable button
#define button_pin 		10	// Using on-board button, specify attached pin, transmitting
#define is_ishield      0	// 1 to specify using Ishield (should enable only wifi as communication platform)
#define is_multiplexer  0	// 1 if tca9548a Multiplexer is being used. (Further customization in advanced options)
#define is_sapflow      1
#define is_evaporimeter 0
#if is_wifi == 1
	#define DEFAULT_MODE      WPA_CLIENT_MODE	// AP_MODE, WPA_CLIENT_MODE or WEP_CLIENT_MODE
	#define DEFAULT_NETWORK   "OPEnS"			// Network SSID / name
	#define DEFAULT_PASSWORD  "arduino101"		// Network password
#endif
#define enable_hub_scripts 0
#define advanced_interdev_comm   0	// Used for Max-like functionality
#define build_actuator_cmd_funcs 0  // 1 to include file to make commands for Loom actuators
#define wake_delay 0	// 1 to enable wait 5 seconds upon awaking from sleep to start serial
#if CHANNEL == -1
	#define INIT_INST    3	// Initial device instance number (normally 1-8 when using channels)
	#define INIT_PORT 9443	// Initial device UDP port (normally 1-8 when using channels)
#endif
#if is_wifi == 1
	#define advanced_interdev_comm 1  // Enable for full Max support
#endif
#if is_rtc == 1
	#define RTC_pin 6
	#define is_rtc3231 0 	// RTC DS 3231 Featherwing
	#define is_rtc8523 1	// RTC Adalogger Featherwing with PCF8523 RTC (the one with SD card)
#endif
#if is_multiplexer == 1
	#define UPDATE_PERIOD 5000		// Milliseconds between multiplexer sensor list being updated
	#define is_tsl2591         1	// Lux Sensor
	#define is_tsl2561         1	// Lux Sensor
	#define is_fxos8700        1	// Accelerometer / Magnetometer
	#define is_fxas21002       1	// Gyroscope
	#define is_zxgesturesensor 1	// ZX_Distance Sensor
	#define is_sht31d          1	// Temperature / Humidity
	#define is_mb1232          1	// Sonar
	#define is_mpu6050         1	// Accelerometer / Gyroscope
	#define is_lis3dh          1    // Accelerometer
	#define is_ms5803          1	// Pressure Sensor
#endif
#if is_ishield == 1
	#define is_button   1			// 1 to enable button
	#define button_pin  10
	#define is_mpu6050  0			// Enables MPU6050 on Ishield
	#define is_neopixel 1			// Toggle based on whether Neopixels are being used
	#if is_neopixel == 1			// Which Ishield ports to enable Neopixels for
		#define NEO_0   0			// Port 0 (A0, closest to end of Ishield)
		#define NEO_1   0			// Port 1 (A1, middle port)
		#define NEO_2   1			// Port 2 (A2, port closest to MPU6050)
	#endif
#endif
#if is_sapflow == 1
	#define hub_node_type    0      // 0: hub, 1: node
  #define probe_type       0      // 0:TDM, 1: HRM
	#define CHANNEL          7      // Channel to use. Set to 1-8 for channels A-H, respectively. Alternatively can define to -1 to used advanced option INIT_INST
  #define REQUEST_SETTINGS 0      // 1 to request channel settings from Max Channel Manager, 0 to not
  #define AUTO_NAME        0      // 1 to enable naming device based on configured settings (if not set manual name in advanced options)
  #define is_lora          1      // enable LoRa
  #define is_rtc           1      // enable rtc
  #define is_sd            1      // enable microsd logger
   char FileName[]       =     "HUB0911.CSV";
  #if hub_node_type == 0       // if is hub
    #define is_ethernet   0
    #define is_fona       1
    #define is_pushingbox 1
    #if is_pushingbox == 1
      #define spreadsheet_id "17XjrTjXENChYsHMVvKgePg8rsohwz0hyASkdeZZKROk"   // This is Dongjun's Sapflow spreadsheet
      char device_id[]   =   "v4099B684340616E";
    #endif // of is_pushingbox
  #elif hub_node_type == 1     // if is node
    #define num_analog    2      // two temperature sensors
    #define is_sht31d     1      // Ambient Temperature / Humidity
    #define is_decagon    1      // Soil moisture
    #define heatpulse     2500   // For HRM probe heat pulse (e.g 2500:2.5 sec)
    #define senddelay     1800000 // send data every 2500(=2.5s), 60000(=1m), 300000ms(=5m), 600000ms(=10m), 900000ms(=15m)
    #if probe_type == 0      // 0:TDM, 1: HRM
      #define heatduration  240000  // Turn on heater for 4 min
    #elif probe_type == 1
      #define heatduration  120000  // Turn on heater for 2 min
    #endif //of probe_type
  #endif // of hub_node_type
  #if probe_type == 0
    #define CUSTOM_NAME      "TDM"  // This is only used if Auto_name is set to be 0
	#elif probe_type == 1
    #define CUSTOM_NAME      "HRM"  // This is only used if Auto_name is set to be 0
  #endif // of probe_type
  #if is_rtc == 1
    #define RTC_pin          6
    #define is_rtc3231       0  // RTC DS 3231 Featherwing
    #define is_rtc8523       1  // RTC Adalogger Featherwing with PCF8523 RTC (the one with SD card)
  #endif //of is_rtc
#endif // of is_sapflow
#if is_evaporimeter == 1
	#define hub_node_type 1
	#define is_lora 1
	#define is_tsl2561 1
		#define is_tsl2561_low   1
		#define is_tsl2561_float 1
		#define is_tsl2561_high  0
	#define is_hx711 1
	#if is_hx711 == 1
		#define hx711_calibration 961.275 // grams
	#endif
	#define is_sht31d 1
	#define is_rtc 1
	#if is_rtc == 1
		#define RTC_pin    6
		#define is_rtc3231 1
		#define is_rtc8523 0
	#endif
	#define is_button  0
#endif
#if is_lora == 1
	#define LORA_HUB_ADDRESS  0			// Use 0-9 for SERVER_ADDRESSes
	#define LORA_NODE_ADDRESS 10			// 10 CLIENT_ADDRESSes belong to each SERVER_ADDRESS,
	#define RF95_FREQ      915.0		// Hardware specific, Tx must match Rx
#endif
#if is_nrf == 1
	#define NRF_HUB_ADDRESS 1			// Use 0-9 for SERVER_ADDRESSes
	#if hub_node_type == 1
		#define NRF_NODE_ADDRESS 0
	#endif
#endif
#if is_ethernet == 1
	#include <Ethernet2.h>				// (this is needed for IPAddress object below, do not remove)
	byte mac[] = {0x00, 0x23, 0x12, 0x12, 0xCE, 0x7D};    // mac address of Ethernet port
	IPAddress ip(128,193,56,138); 						  // device's IP address  				try to make this a string, so #include can be move to ethernet file
#endif
#if is_fona == 1
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

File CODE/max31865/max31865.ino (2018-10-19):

/*************************************************** 
  This is a library for the Adafruit PT100/P1000 RTD Sensor w/MAX31865

  Designed specifically to work with the Adafruit RTD Sensor
  ----> https://www.adafruit.com/products/3328

  This sensor uses SPI to communicate, 4 pins are required to  
  interface
  Adafruit invests time and resources providing this open source code, 
  please support Adafruit and open-source hardware by purchasing 
  products from Adafruit!

  Written by Limor Fried/Ladyada for Adafruit Industries.  
  BSD license, all text above must be included in any redistribution
 ****************************************************/

#include <Adafruit_MAX31865.h>

// Use software SPI: CS, DI, DO, CLK
Adafruit_MAX31865 max0 = Adafruit_MAX31865(A0, 9, 6, 5);
Adafruit_MAX31865 max1 = Adafruit_MAX31865(A1, 9, 6, 5);

// use hardware SPI, just pass in the CS pin
#define PIN_SPI_MISO         (22u)
#define PIN_SPI_MOSI         (23u)
#define PIN_SPI_SCK          (24u)
//Adafruit_MAX31865 max0 = Adafruit_MAX31865(A3, PIN_SPI_MOSI, PIN_SPI_MISO, PIN_SPI_SCK);
//Adafruit_MAX31865 max1 = Adafruit_MAX31865(A5, PIN_SPI_MOSI, PIN_SPI_MISO, PIN_SPI_SCK);

// The value of the Rref resistor. Use 430.0 for PT100 and 4300.0 for PT1000
#define RREF      430.0
// The 'nominal' 0-degrees-C resistance of the sensor
// 100.0 for PT100, 1000.0 for PT1000
#define RNOMINAL0  101.45
#define RNOMINAL1  101.60

void setup() {
  Serial.begin(9600);
  Serial.println("Adafruit MAX31865 PT100 Sensor Test!");
  max0.begin(MAX31865_2WIRE);  // set to 2WIRE or 4WIRE as necessary
  max1.begin(MAX31865_2WIRE);  // set to 2WIRE or 4WIRE as necessary
  max0.clearFault();
  max1.clearFault();
}


void loop() {
  uint16_t rtd0 = max0.readRTD();
  uint16_t rtd1 = max1.readRTD();

// Probe 0
  Serial.println("[Probe 0]");
  Serial.print("RTD value: "); Serial.println(rtd0);
  
  float ratio0 = rtd0;
  ratio0 /= 32768;
  
  Serial.print("Ratio = "); Serial.println(ratio0,8);
  Serial.print("Resistance = "); Serial.println(RREF*ratio0,8);
  Serial.print("Temperature = "); Serial.println(max0.temperature(RNOMINAL0, RREF));

  // Check and print any faults
  uint8_t fault0 = max0.readFault();
  if (fault0) {
    Serial.print("Fault 0x"); Serial.println(fault0, HEX);
    if (fault0 & MAX31865_FAULT_HIGHTHRESH) {
      Serial.println("RTD High Threshold"); 
    }
    if (fault0 & MAX31865_FAULT_LOWTHRESH) {
      Serial.println("RTD Low Threshold"); 
    }
    if (fault0 & MAX31865_FAULT_REFINLOW) {
      Serial.println("REFIN- > 0.85 x Bias"); 
    }
    if (fault0 & MAX31865_FAULT_REFINHIGH) {
      Serial.println("REFIN- < 0.85 x Bias - FORCE- open"); 
    }
    if (fault0 & MAX31865_FAULT_RTDINLOW) {
      Serial.println("RTDIN- < 0.85 x Bias - FORCE- open"); 
    }
    if (fault0 & MAX31865_FAULT_OVUV) {
      Serial.println("Under/Over voltage"); 
    }
    max0.clearFault();
  }
  delay(1000);
  //probe 1
  
  Serial.println("[Probe 1]");
  Serial.print("RTD value: "); Serial.println(rtd1);
  float ratio1 = rtd1;
  ratio1 /= 32768;
  Serial.print("Ratio = "); Serial.println(ratio1,8);
  Serial.print("Resistance = "); Serial.println(RREF*ratio1,8);
  Serial.print("Temperature = "); Serial.println(max1.temperature(RNOMINAL1, RREF));

  // Check and print any faults
  uint8_t fault1 = max1.readFault();
  if (fault1) {
    Serial.print("Fault 0x"); Serial.println(fault1, HEX);
    if (fault1 & MAX31865_FAULT_HIGHTHRESH) {
      Serial.println("RTD High Threshold"); 
    }
    if (fault1 & MAX31865_FAULT_LOWTHRESH) {
      Serial.println("RTD Low Threshold"); 
    }
    if (fault1 & MAX31865_FAULT_REFINLOW) {
      Serial.println("REFIN- > 0.85 x Bias"); 
    }
    if (fault1 & MAX31865_FAULT_REFINHIGH) {
      Serial.println("REFIN- < 0.85 x Bias - FORCE- open"); 
    }
    if (fault1 & MAX31865_FAULT_RTDINLOW) {
      Serial.println("RTDIN- < 0.85 x Bias - FORCE- open"); 
    }
    if (fault1 & MAX31865_FAULT_OVUV) {
      Serial.println("Under/Over voltage"); 
    }
    max1.clearFault();
  }
  Serial.println();
  delay(2000);
}

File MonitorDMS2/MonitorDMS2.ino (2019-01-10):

/*
  MonitorDMS
  Reads an analog input using a ADS1231, converts it to strain, and prints the result to the serial monitor.
 
 This example code is in the public domain.
 */

 #include <ADS1231.h>

 
 ADS1231 myDMS;  // create ADS1231 object to monitor a DMS  

// the setup routine runs once when you press reset:
void setup() {
  // initialize serial communication at 115200 bits per second:
  Serial.begin(115200);
//  SPI.begin();
//  digitalWrite(SS, LOW);
  //ADS DRDY/DOUT <--------> Arduino Pin 12, ICSP-1 (MISO)
  //ADS SCLK <-------------> Arduino Pin 13, ICSP-3 (SCK)
  //ADS PDWN <-------------> Arduino Pin 10 (SS)
  // attach the DMS on pin SCK, MISO, SS
//  myDMS.attach( 13 , 12 , 10 );
  myDMS.attach( SCK , MISO , 10 );
  Serial.println("ADS1231");
  Serial.println("time [ms] , sensor , dt sensor read [us]");
}

// the loop routine runs over and over again forever:
void loop() {
  // check for data ready
//  digitalWrite(SS,LOW);
  if( myDMS.check() ) {
    // get start time of read
    unsigned long timeStart = micros();
    // read the input on ADS1231:
    long sensorValue = myDMS.readData();
    // get final time of read
    unsigned long timeEnd = micros();
    // print out the time, the value read and time required for read:
    Serial.print(millis());
    Serial.print(" , ");
    Serial.print(sensorValue);
    Serial.print(" , ");
    Serial.println(timeEnd-timeStart);
  }

//  digitalWrite(SS,HIGH);
}

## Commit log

2018-08-08 Add PCB files
    [Viper0.4.1 tmd probe (6-12).brd, Viper0.4.1 tmd probe (6-12).sch, sapflux.brd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]
2018-08-08 add cad files
    [Sap_Base_Bottom_v2.stl, Sap_Base_Top_v2.stl]
2018-08-16 fix minor error
    [LOG0806.CSV, Sap_Base_Top_v2.stl, TDM_CAL.xlsx]
2018-09-17 Update all of files
    [HRM0816.CSV, HRM0816_wplot.csv, HRM0821.CSV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]
2018-09-19 Fix PCB GERBER
    [MAX31865.brd, MAX31865.sch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]
2018-10-13 Add MAX31865 functionality
    [MAX31865.brd, MAX31865.sch, TDM_CAL.xlsx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]
2018-10-16 Hardware SPI doesn't work with other SPI deivce
    [SD_MAX31865.ino]
2018-10-16 RTD Calibration code
2019-01-10 Add wiring pictures
2019-07-03 Cleaning up and consolidating the log data
    [HRM0816.CSV, HRM0816_wplot.csv, HRM0821.CSV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]

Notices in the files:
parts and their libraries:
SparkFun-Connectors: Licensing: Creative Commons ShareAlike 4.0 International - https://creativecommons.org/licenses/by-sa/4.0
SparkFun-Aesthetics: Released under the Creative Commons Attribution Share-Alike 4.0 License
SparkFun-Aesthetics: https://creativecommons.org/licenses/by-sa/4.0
